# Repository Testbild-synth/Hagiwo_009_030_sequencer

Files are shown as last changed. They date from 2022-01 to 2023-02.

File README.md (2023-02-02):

# HAGIWO 6 Channel Sequencer / Euclidean Rhythm Sequencer

Gif of the sequencer running

This project is a through hole PCB version the HAGIWO 009 [six channel gate sequencer](https://www.youtube.com/watch?v=YszdC8YdFl0&t=29s) and 030 [euclidean rythm sequencer](https://www.youtube.com/watch?v=lkoBfiq6KPY) eurorack synth modules. the modules run on an Arduino Nano and uses a [0.96 inch Oled I2C Display](https://www.ebay.de/itm/255303518853). The exact brand is not important, just make sure it is 128/64 pixels and has an SSD1306 driver.
Also, pinout should match the one specified on the PCB:
I saw that there are some modules that have VCC-GND-SCL-SDA, but we need GND-VCC-SCL-SDA

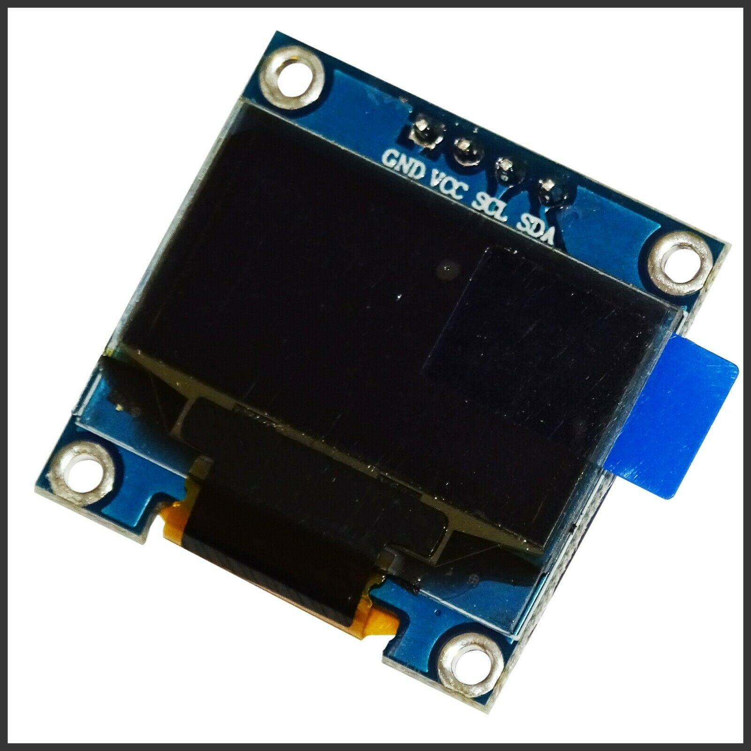
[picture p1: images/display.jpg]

Since both modules use the same hardware, I made it so that the panel pcb is flippable to reflect both functions.

## Status: Don't build this right now, new revision is coming soon!

## PCB and Hardware

You can find the schematic and BOM in the root folder.
For the PCBs, the module has one circuit PCB and one panel PCB. 
You can order them on any common PCB manufacturing service, I used [JLCPCB](https://jlcpcb.com/).
Standard settings should be fine, but if you have exposed copper on the panel you should go with a lead free surface finish (ENIG/Leadfree HASL).

If the panel sizes are not recognized correctly (may happen with my export sometimes) just put 128.5x30.

Use the panel_pcb.zip gerbers if you want a panel with exposed solder mask (so silver letters for title) but then make sure to choose a lead free finish cause health reasons.
If you don't want that, use the "panel_no_silver.zip" version.

The panel PCB is switchable to reflect the function depending on the firmware you want to use.    

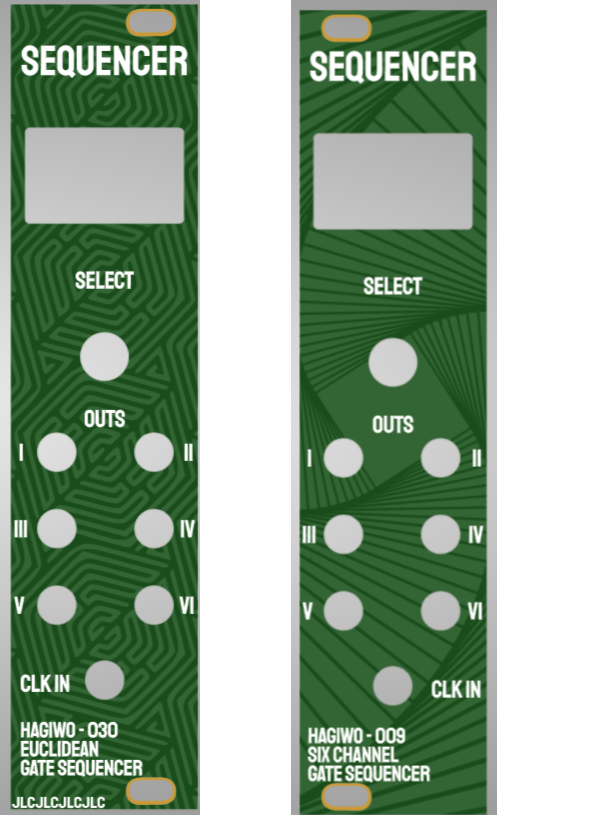
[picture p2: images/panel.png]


## Assembly Instructions

The PCB is relatively simple to build, all the components are through-hole soldering.
It is easiest to start first with the resistors and capacitors, then the headers, and then the jacks at the end.    

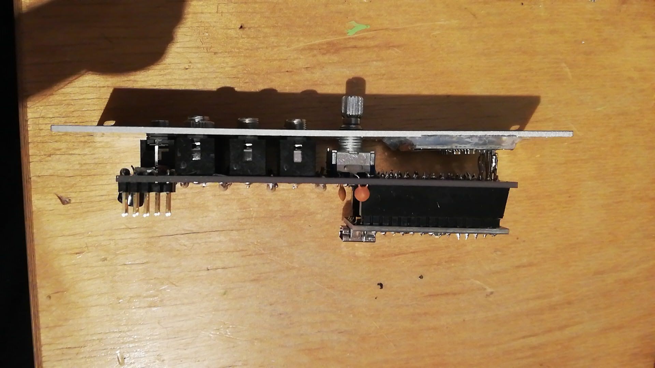
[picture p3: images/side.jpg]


The only thing that is a bit tricky is the screen, since depending on your components it can stand out on the top. 
To prevent this, you can try soldering the display directly on the PCB.    

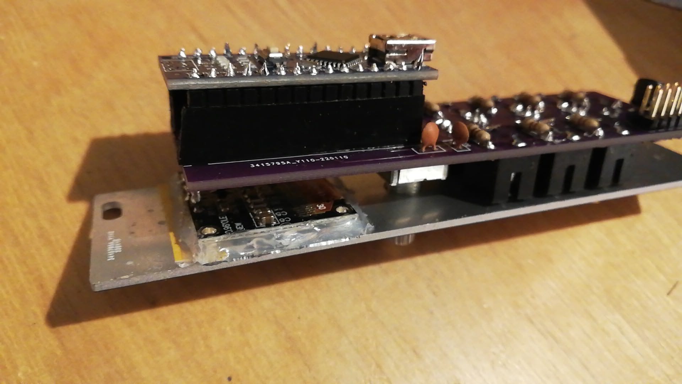
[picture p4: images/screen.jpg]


Another optional but good idea is glueing the screen to the panel first before mounting to ensure it is positioned directly behind the cutout.
Downside to glueing is obviously not being able to flip the panel when flashing the firmware so only do it if you build two or are sure you dont need the other side of the panel.

## Arduino Code and Testing

There are three Arduino files included in this project:
- The project file for the six channel drum sequencer (six_channel_sequencer.ino)
- The project file for the euclidean sequencer        (euclid_sequencer.ino)
- A file for testing in/outputs to make sure you soldered everything correctly (test_circuit.ino). This file prints to the serial to test inputs and sets the digital outputs.

You need the [Adafruit_SSD1306](https://www.arduino.cc/reference/en/libraries/adafruit-ssd1306/) and [encoder](https://www.arduino.cc/reference/en/libraries/encoder/) libraries.
I also changed it such that is uses FastGPIO instead of DigitalRead (to recude latency, which was probably not a concern in the first place but I do it in all my arduino projects). See the [FastGPIO](https://github.com/pololu/fastgpio-arduino) repo.

One important change from HAGIWO's code is the introduction of the parameter ENCODER_COUNT_PER_ROTATION. 
Rotation encoders come in different versions, some have one click per rotation, some have two, others even have four. If you see multiple messages during a single turn while running the test_circuit file, set this parameter higher in all files before uploading.

For the six channel sequencer, there are preprogrammed pattern banks you can change (bnk1_ptn, bnk2_ptn, etc.). The patterns are in hexadecimal and represent 16 binary numbers. So for example if the number says 0x8888, this means 1000100010001000, meaning a four on the floor pattern. Use a [hex to binary converter](https://www.rapidtables.com/convert/number/hex-to-binary.html) to help you convert it.

HAGIWO's version only updates the screen when the clock comes in, but I think this makes for a bad user experience so I changed it to update when you turn the encoder as well. 

## TODO:
- Maybe add more rhythm patterns to 6 channel sequencer (taking suggestions here if people want to help me with the work)

## Successful builds
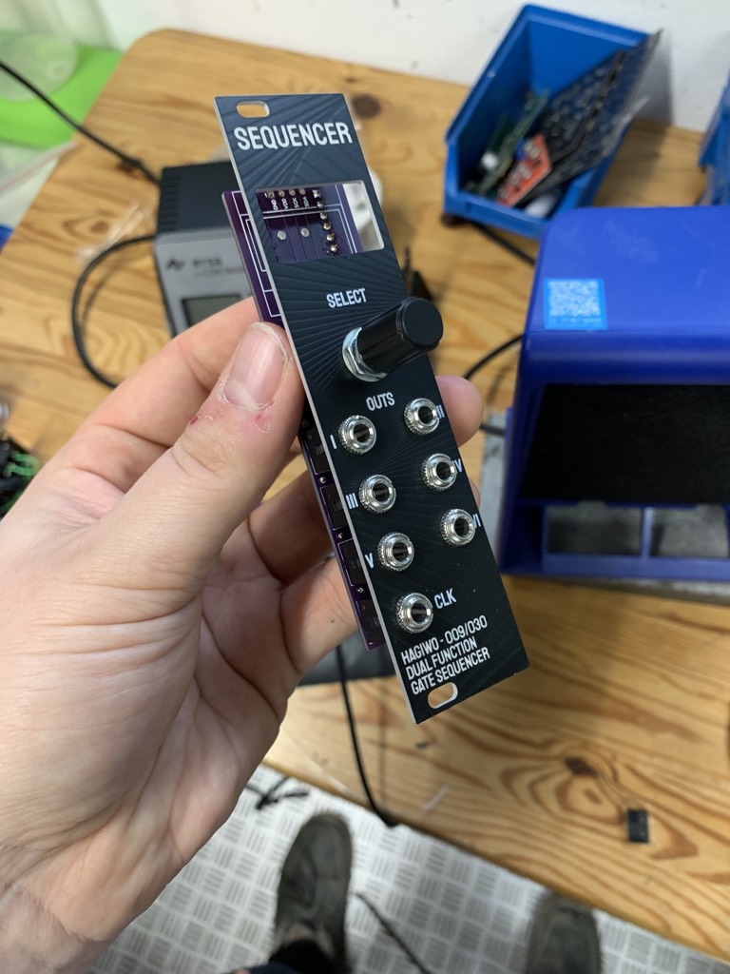
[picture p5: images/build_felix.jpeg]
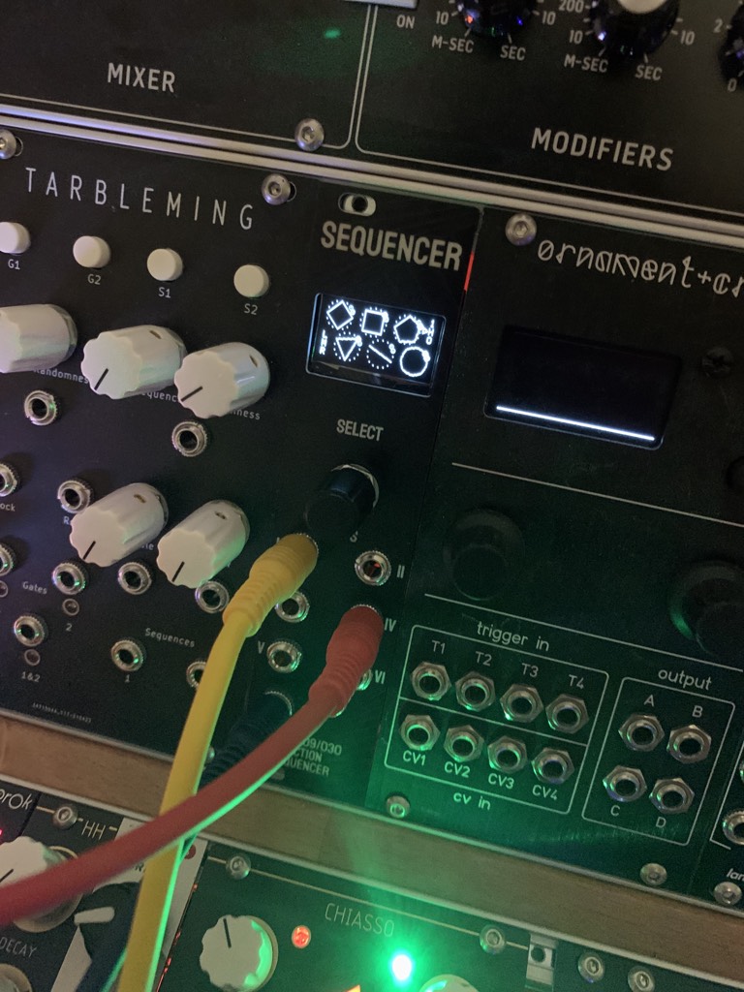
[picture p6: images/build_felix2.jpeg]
 

By Felix W.

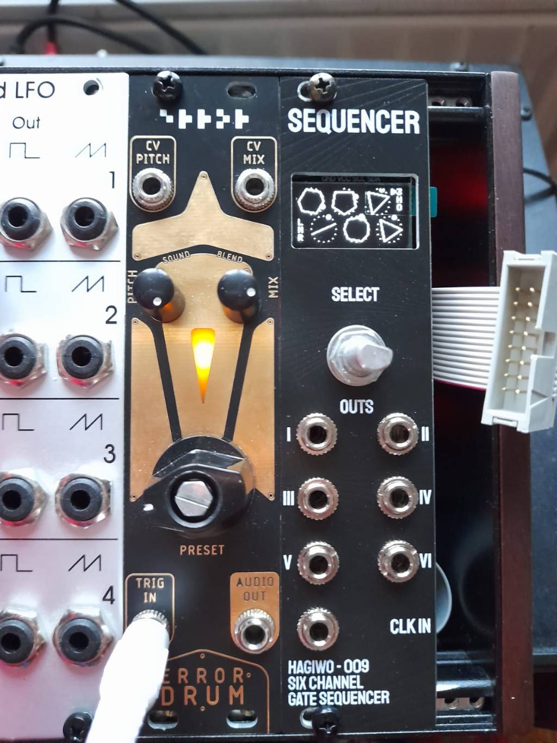
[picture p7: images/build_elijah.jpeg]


By Elija

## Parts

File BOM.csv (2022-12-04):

Name | Designator
ALPS_ENCODER+PUSHSWITCH | ENC
10n | C1,C2
10u | C3
BAT43 | D1,D2
EURORACK_POWERHEADER_V2 | EP1
0.96OLEDDisplay SSD1306 | H1
THONKICONN_1 | J1-J7
2.2k | R1,R2,R3,R4,R5,R6,R9
3k3 | R7,R8
100k | R10
ARDUINO_NANO | U1

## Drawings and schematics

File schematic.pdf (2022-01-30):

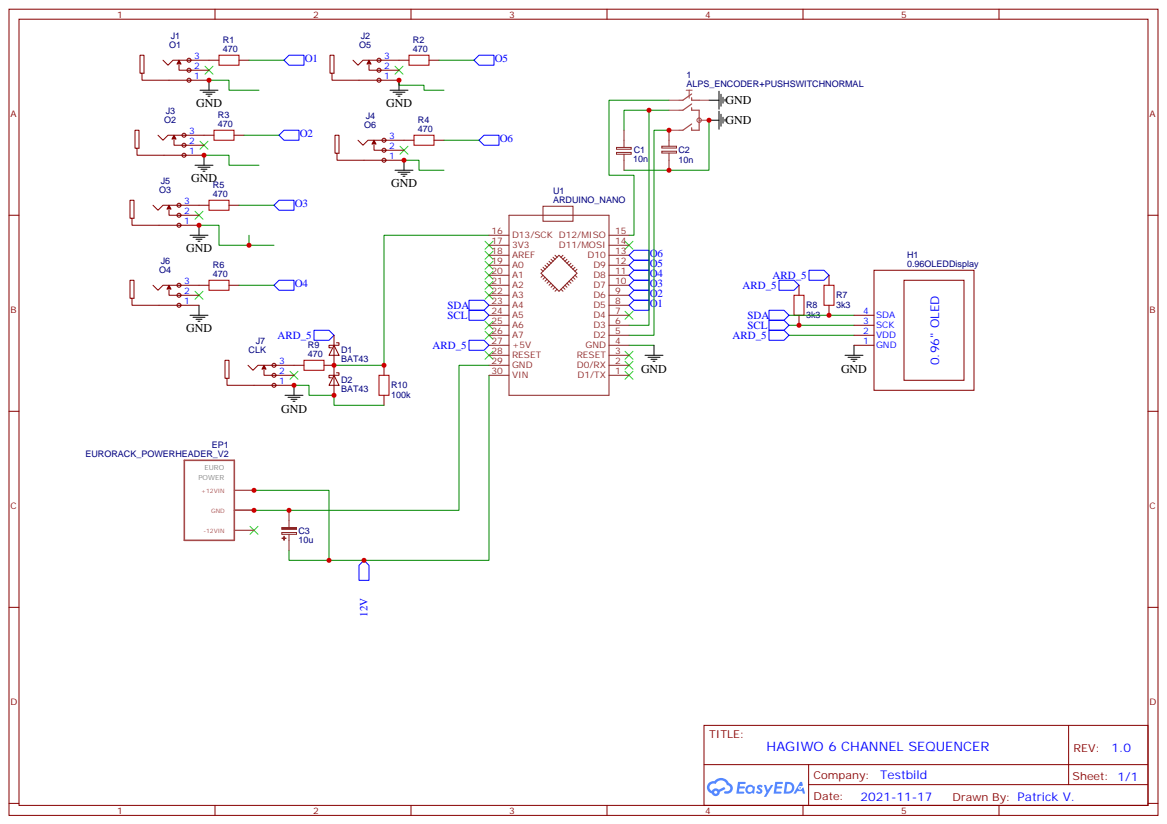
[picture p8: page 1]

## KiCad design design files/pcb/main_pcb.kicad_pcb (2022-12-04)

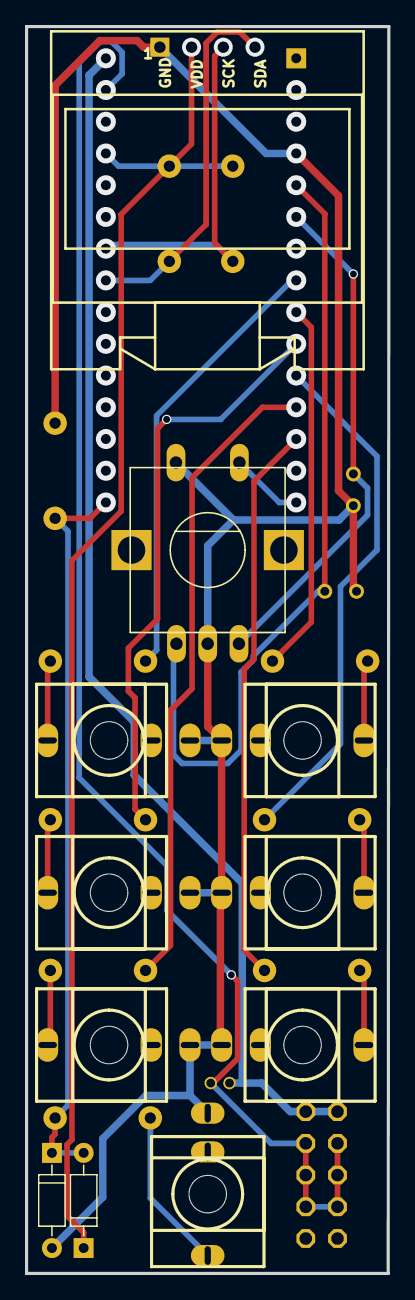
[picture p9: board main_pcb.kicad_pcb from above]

Board: 2 copper layers, 29.0 x 99.8 mm, 24 parts (0 on the bottom side), 14 nets.

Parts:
1: ALPS_ENCODER+PUSHSWITCHNORMAL; ENCODER+SWITCH
C1, C2: 10n; RAD-0.1
C3: 10u; CAP-D4.0×F1.5
D1, D2: BAT43; D_DO-35_SOD27_P7.62MM_HORIZONTAL
EP1: EURORACK_POWERHEADER_V2; EURORACK_POWER_V2
J1: O1; THONKICONN_1
J2: O5; THONKICONN_1
J3: O2; THONKICONN_1
J4: O6; THONKICONN_1
J5: O3; THONKICONN_1
J6: O4; THONKICONN_1
J7: CLK; THONKICONN_1
R1, R2, R3, R4, R5, R6, R9: 2.2k; R_AXIAL-0.3
R7, R8: 3k3; R_AXIAL-0.3
R10: 100k; R_AXIAL-0.3

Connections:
12V: C3.1, EP1.12
ARD_5: D1.1, R7.1, R8.1
C1_2: 1.B, C1.2
C2_1: 1.A, C2.1
EP1_GND0: C3.2, EP1.GND0, EP1.GND1, EP1.GND2, EP1.GND3, EP1.GND4, EP1.GND5
GND: 1.C, 1.D, C1.1, C2.2, D2.2, J1.1, J2.1, J3.1, J4.1, J5.1, J6.1, J7.1, R10.2
R1_2: J1.3, R1.2
R2_2: J2.3, R2.2
R3_2: J3.3, R3.2
R4_2: J4.3, R4.2
R5_2: J5.3, R5.2
R6_2: J6.3, R6.2
R9_2: J7.3, R9.2
R10_1: D1.2, D2.1, R9.1, R10.1

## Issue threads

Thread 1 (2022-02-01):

Would it be posible to access your design files?

KeLaiFu, 2022-02-01:
First of all, thanks for making the Hagiwo modules accessable to those of us too lazy to use veroboard, really happy to see them being upped to github.

I have just ordred a few of his modules from another chap doing the same and in the process I edited them a little, just to make the jack spacing and screen height etc the same as some of my current modules in the rack. A bit of a first world OCD problem I know, but would it be posible to get the kicad/eagle files of the ones you made added to the repo so I could do the same and keep everthing in the same style?

Testbild-synth, 2022-02-01:
Hey :) So I use easyeda for my pcbs and inkscape for my panels. The panels I can give you either as an inkscape project file or converted to a kicad project, for the pcbs I have too look what the best way to export them is. I think easyeda does kicad and eagle export but I've tried it once and it seemed a bit buggy. with that in mind, what do you think is the best format to upload the design files

KeLaiFu, 2022-02-02:
I've used the web based easyeda > kicad converter without problems, so just uploading your files without any changes should be fine.

Testbild-synth, 2022-02-03:
@KeLaiFu I uploaded all the files, check again and if these are helpful for you I can close the issue

KeLaiFu, 2022-02-04:
I had a quick look as I am on my way out of the house, looks fine, thanks so much!

Closed 2022-02-07.

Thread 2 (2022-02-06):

Gerber and Production file mismatch

DeadPanne, 2022-02-06:
To start, Thank you for your amazing work on the HAGIWO designs!
I was planning on doing some modification of the PCB, but when looking at the design files for this repo, it seems like you've uploaded the production files for the [Eurorack Quantizer](https://github.com/Testbild-synth/HAGIWO-029-033-Eurorack-quantizer) as it uses a Seeeduino Xiao in the PCB

Thanks in advance

Testbild-synth, 2022-02-07:
ok sorry, I uploaded multiple projects these last few days and must have gotten confused. now it should be fine

Testbild-synth, 2022-02-09:
i will close this for now, if I made another mistake just tell me

Closed 2022-02-09.

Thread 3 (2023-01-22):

The sequences doesn't respond to the clock signal

dubbeljoe2002, 2023-01-22:
When I connect all, programis running, but is not responding to the clock signal.
checked hardware and  solder joins, all OK.

Testbild-synth, 2023-01-22:
So the clock input is connected to D13, which on some arduinos causes problems when used as an input because it is also connected to the internal LED. I will change it to use a different pin in the next revision and leave this issue open until then, but for now a quick fix you can try is scratching off or desoldering the LED on your nano (the one with the L next to it).

More information is here: https://forum.arduino.cc/t/arduino-nano-pin-d13-usage/474254

Testbild-synth, 2023-01-22:
Also I just saw that there might be a ground connection issue, please make sure that on the board you have the jack grounds are properly connected to the arduino ground and the power ground

dubbeljoe2002, 2023-01-26:
> Also I just saw that there might be a ground connection issue, please make sure that on the board you have the jack grounds are properly connected to the arduino ground and the power ground

thanks for the tips.
I desoldered the L Led on my aliexpress arduino nano and checked the ground connectors.
unfortunately if did not give a solution.
Don't feel obligated to fix this. Maybe it gives me the right push to dive into the code and learn something ;-)

dtk1985, 2024-11-25:
Hi @Testbild-synth , first of all thanks for the gerbers. I just manged to solder up the board which I had lying around for a year. I think I had the same problem as @dubbeljoe2002, the module was not responding to the clock signal from the Meebilt LFO at first. But after removing the arduino's LED resistor and making sure all grounds are connected, it started working. Yay!

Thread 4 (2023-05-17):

Please move outputs 2,4,6 to PWM pins and add optional LPFs

BenignCremator, 2023-05-17:
What I would like to be able to do is write alternative code for this module that would group pairs of outputs (1 and 2, 3 with 4, 5 with 6) into gate and CV pairs, allowing the module to output three tonal channels instead of six atonal ones.  For this, output 2, 4, and 6 need to be moved onto PWM pins.  If I am reading the schematic correctly, outputs 2 and 6 are currently on PWM pins, and only D4 needs to be changed.  One way to do this is by swapping D8 and D9, or moving outputs 4, 5, and 6 to D9,  D10, and D11.  Also, since this would require using PWM output to generate a CV signal, low pass filters would be a good idea on those pins.  A simple resistor-capacitor filter should suffice, though adding an on-board op-amp for buffering would be a nice to have.  Is this a do-able and reasonable?  Please let me know and thanks in advance.

Testbild-synth, 2023-05-17:
hi,
first of all thank you for your interest in the module and willingness to contribute!

since I planned to do a redesign of this anyway I might as well do that.
keep in mind that running the PWM loops with an I2C screen connection at the same time might get a bit iffy in terms of programming it (I have used SPI screens before and had quite a few problems with audio artifacts/noise being introduced.) If you want we can coordinate on this, I'd be happy to give you other contact details :)

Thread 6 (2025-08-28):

Low output to trigger drum modules

mjlouer-png, 2025-08-28:
Hi Testbild.

Ive build the gate sequencer from Hagiwo a few months ago and it works but it has issues.
The main one is that when i turn on my modular synth, the oled stays black. The module does not start. After uploading the code everything works as normal. Then after some time (sometimes a few hours, days or weeks) for some yet unknown reason the module does not start. Re-uploading the sketch and boom! It works. So apperantly the Arduino Nano loses its programming.

While searching the internet i stumbled upon your github and tried your code.
The Arduino starts, i see the dots on the screen but it does nog trigger any of my, mostly Moritz Klein's drum modules. So apperantly the gate output voltages are too low??. For testing i tried the HIP bass drum module as the THUD sets the treshold and when fully open the potmeter, it starts to trigger. So the module works but to low output. How can i increase or set out voltage tresholds? Some line in the code i hope?

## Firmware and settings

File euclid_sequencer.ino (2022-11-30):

//Encoder setting
#define  ENCODER_OPTIMIZE_INTERRUPTS //countermeasure of encoder noise
#include <Encoder.h>
#include <FastGPIO.h>

//Oled setting
#include<Wire.h>
#include<Adafruit_GFX.h>
#include<Adafruit_SSD1306.h>

#define OLED_ADDRESS 0x3C
#define SCREEN_WIDTH 128
#define SCREEN_HEIGHT 64
#define ENCODER__PIN1 2
#define ENCODER_PIN2  3
#define ENCODER_SW_PIN 12
#define CLK_PIN 13
#define ENCODER_COUNT_PER_CLICK 4

#define OUT_CH1 5
#define OUT_CH2 6
#define OUT_CH3 7
#define OUT_CH4 8
#define OUT_CH5 9
#define OUT_CH6 10

Adafruit_SSD1306 display(SCREEN_WIDTH, SCREEN_HEIGHT, &Wire, -1);

//rotery encoder
Encoder myEnc(ENCODER__PIN1, ENCODER_PIN2);//use 3pin 2pin
int oldPosition  = -999;
int newPosition = -999;
int i = 0;

//push button
bool sw = 0;//push button
bool old_sw;//countermeasure of sw chattering
unsigned long sw_timer = 0;//countermeasure of sw chattering



//each channel param
byte hits[6] = { 4, 4, 5, 3, 2, 16};//each channel hits
byte offset[6] = { 0, 2, 0, 8, 3, 9};//each channele step offset
bool mute[6] = {0, 0, 0, 0, 0, 0}; //mute 0 = off , 1 = on
byte limit[6] = {16, 16, 16, 16, 16, 16};//eache channel max step

//Sequence variable
byte j = 0;
byte k = 0;
byte m = 0;
byte buf_count = 0;

const static byte euc16[17][16] PROGMEM = {//euclidian rythm
 {0, 0, 0, 0, 0, 0, 0, 0, 0, 0, 0, 0, 0, 0, 0, 0},
 {1, 0, 0, 0, 0, 0, 0, 0, 0, 0, 0, 0, 0, 0, 0, 0},
 {1, 0, 0, 0, 0, 0, 0, 0, 1, 0, 0, 0, 0, 0, 0, 0},
 {1, 0, 0, 0, 0, 1, 0, 0, 0, 0, 1, 0, 0, 0, 0, 0},
 {1, 0, 0, 0, 1, 0, 0, 0, 1, 0, 0, 0, 1, 0, 0, 0},
 {1, 0, 0, 1, 0, 0, 1, 0, 0, 1, 0, 0, 1, 0, 0, 0},
 {1, 0, 0, 1, 0, 1, 0, 0, 1, 0, 0, 1, 0, 1, 0, 0},
 {1, 0, 0, 1, 0, 1, 0, 1, 0, 0, 1, 0, 1, 0, 1, 0},
 {1, 0, 1, 0, 1, 0, 1, 0, 1, 0, 1, 0, 1, 0, 1, 0},
 {1, 0, 1, 1, 0, 1, 0, 1, 0, 1, 1, 0, 1, 0, 1, 0},
 {1, 0, 1, 1, 0, 1, 0, 1, 1, 0, 1, 1, 0, 1, 0, 1},
 {1, 0, 1, 1, 0, 1, 1, 0, 1, 1, 0, 1, 1, 0, 1, 1},
 {1, 0, 1, 1, 1, 0, 1, 1, 1, 0, 1, 1, 1, 0, 1, 1},
 {1, 0, 1, 1, 1, 1, 0, 1, 1, 1, 1, 0, 1, 1, 1, 1},
 {1, 0, 1, 1, 1, 1, 1, 1, 1, 0, 1, 1, 1, 1, 1, 1},
 {1, 1, 1, 1, 1, 1, 1, 1, 1, 1, 1, 1, 1, 1, 1, 0},
 {1, 1, 1, 1, 1, 1, 1, 1, 1, 1, 1, 1, 1, 1, 1, 1}
};
bool offset_buf[6][16];//offset buffer , Stores the offset result

bool trg_in = 0;//external trigger in H=1,L=0
bool old_trg_in = 0;
byte playing_step[6] = {0, 0, 0, 0, 0, 0}; //playing step number , CH1,2,3,4,5,6
unsigned long gate_timer = 0;//countermeasure of sw chattering

//display param
byte select_menu = 0;//0=CH,1=HIT,2=OFFSET,3=LIMIT,4=MUTE,5=RESET,
byte select_ch = 0;//0~5 = each channel -1 , 6 = random mode

unsigned int last_refresh = 0;
const int  max_refresh_time = 70;
bool disp_refresh = 1;//0=not refresh display , 1= refresh display , countermeasure of display refresh bussy

const byte graph_x[6] = {0, 40, 80, 15, 55, 95};//each chanel display offset
const byte graph_y[6] = {0, 0,  0,  32, 32, 32};//each chanel display offset

byte line_xbuf[17];//Buffer for drawing lines
byte line_ybuf[17];//Buffer for drawing lines

const byte x16[16] = {15,  21, 26, 29, 30, 29, 26, 21, 15, 9,  4,  1,  0,  1,  4,  9};//Vertex coordinates
const byte y16[16] = {0,  1,  4,  9,  15, 21, 26, 29, 30, 29, 26, 21, 15, 9,  4,  1};//Vertex coordinates


//random assign
byte hit_occ[6] = {0, 10, 20, 20, 40, 80}; //random change rate of occurrence
byte off_occ[6] = {10, 20, 20, 30, 40, 20}; //random change rate of occurrence
byte mute_occ[6] = {20, 20, 20, 20, 20, 20}; //random change rate of occurrence
byte hit_rng_max[6] = {0, 14, 16, 8, 9, 16}; //random change range of max
byte hit_rng_min[6] = {0, 13, 6, 1, 5, 10}; //random change range of max

byte bar_now = 1;//count 16 steps, the bar will increase by 1.
byte bar_max[4] = {2, 4, 8, 16} ;//selectable bar
byte bar_select = 1;//selected bar
byte step_cnt = 0;//count 16 steps, the bar will increase by 1.

void setup() {
 // OLED setting
 display.begin(SSD1306_SWITCHCAPVCC, 0x3C);
 display.setTextSize(1);
 display.setTextColor(WHITE);
 OLED_display();

 //pin mode setting
 FastGPIO::Pin<ENCODER_SW_PIN>::setInputPulledUp(); //BUTTON
 FastGPIO::Pin<CLK_PIN>::setInput(); // CLK
}

void loop() {
 
 old_trg_in = trg_in;
 oldPosition = newPosition;
 //-----------------Rotery encoder read----------------------
 newPosition = myEnc.read()/ENCODER_COUNT_PER_CLICK;

 if ( newPosition   < oldPosition ) {//turn left
   oldPosition = newPosition;
   disp_refresh = 1;//Enable while debugging.
   if (select_menu != 0) {
     select_menu --;
   }
 }

 else if ( newPosition    > oldPosition ) {//turn right
   oldPosition = newPosition;
   disp_refresh = 1;//Enable while debugging.
   select_menu ++;
 }
 if (select_ch != 6) { // not random mode
   select_menu = constrain(select_menu, 0, 5);
 }
 else  if (select_ch == 6) { // random mode
   select_menu = constrain(select_menu, 0, 1);
 }

 //-----------------push button----------------------

 sw = 1;
 if ((!FastGPIO::Pin<ENCODER_SW_PIN>::isInputHigh()) && ( sw_timer + 300 <= millis() )) { //push button on ,Logic inversion , sw_timer is countermeasure of chattering
   sw_timer = millis();
   sw = 0;
   disp_refresh = 1;//Enable while debugging.
 }

 if (sw == 0) { //push button on
   switch (select_menu) {
     case 0: //select chanel
       select_ch ++;
       if (select_ch >= 7) {
         select_ch = 0;
       }
       break;

     case 1: //hits
       if (select_ch != 6) { // not random mode
         hits[select_ch]++ ;
         if (hits[select_ch] >= 17) {
           hits[select_ch] = 0;
         }
       }
       else  if (select_ch == 6) { // random mode
         bar_select ++;
         if (bar_select >= 4) {
           bar_select = 0;
         }
       }
       break;

     case 2: //offset
       offset[select_ch]++ ;
       if (offset[select_ch] >= 16) {
         offset[select_ch] = 0;
       }
       break;

     case 3: //limit
       limit[select_ch]++ ;
       if (limit[select_ch] >= 17) {
         limit[select_ch] = 0;
       }

       break;

     case 4: //mute
       mute[select_ch] = !mute[select_ch] ;
       break;

     case 5: //reset
       for (k = 0; k <= 5; k++) {
         playing_step[k] = 0;
       }
       break;
   }
 }

 //-----------------offset setting----------------------
 for (k = 0; k <= 5; k++) { //k = 1~6ch
   for (i = offset[k]; i <= 15; i++) {
     offset_buf[k][i - offset[k]] = (pgm_read_byte(&(euc16[hits[k]][i]))) ;
   }

   for (i = 0; i < offset[k]; i++) {
     offset_buf[k][16 - offset[k] + i] = (pgm_read_byte(&(euc16[hits[k]][i])));
   }
 }

 //-----------------trigger detect & output----------------------
 trg_in = FastGPIO::Pin<CLK_PIN>::isInputHigh();//external trigger in
 if (old_trg_in == 0 && trg_in == 1) {
   gate_timer = millis();
   for (i = 0; i <= 5; i++) {
     playing_step[i]++;      //When the trigger in, increment the step by 1.
     if (playing_step[i] >= limit[i]) {
       playing_step[i] = 0;  //When the step limit is reached, the step is set back to 0.
     }
   }
   for (k = 0; k <= 5; k++) {//output gate signal
     if (offset_buf[k][playing_step[k]] == 1 && mute[k] == 0) {
       switch (k) {
         case 0:
           FastGPIO::Pin<OUT_CH1>::setOutputValue(HIGH);
           break;

         case 1:
           FastGPIO::Pin<OUT_CH2>::setOutputValue(HIGH);
           break;

         case 2:
           FastGPIO::Pin<OUT_CH3>::setOutputValue(HIGH);
           break;

         case 3:
           FastGPIO::Pin<OUT_CH4>::setOutputValue(HIGH);
           break;

         case 4:
           FastGPIO::Pin<OUT_CH5>::setOutputValue(HIGH);
           break;

         case 5:
           FastGPIO::Pin<OUT_CH6>::setOutputValue(HIGH);
           break;
       }
     }
   }
   // if the bpm is too high we want to still have output but not update the screen so that the arduino is not busy
   if((millis()-last_refresh) > max_refresh_time){
      disp_refresh = 1;
      last_refresh = millis();
   }
   //Updates the display where the trigger was entered.If it update it all the time, the response of gate on will be worse.

   if (select_ch == 6) {// random mode setting
     step_cnt ++;
     if (step_cnt >= 16) {
       bar_now ++;
       step_cnt = 0;
       if (bar_now > bar_max[bar_select]) {
         bar_now = 1;
         Random_change();
       }
     }
   }
 }

 if  (gate_timer + 100 <= millis()) { //off all gate , gate time is 10msec
   FastGPIO::Pin<OUT_CH1>::setOutputValue(LOW);
   FastGPIO::Pin<OUT_CH2>::setOutputValue(LOW);
   FastGPIO::Pin<OUT_CH3>::setOutputValue(LOW);
   FastGPIO::Pin<OUT_CH4>::setOutputValue(LOW);
   FastGPIO::Pin<OUT_CH5>::setOutputValue(LOW);
   FastGPIO::Pin<OUT_CH6>::setOutputValue(LOW);
 }


 if (disp_refresh == 1) {
   OLED_display();//refresh display
   disp_refresh = 0;
 }
}

void Random_change() { // when random mode and full of bar_now ,
 for (k = 1; k <= 5; k++) {

   if (hit_occ[k] >= random(1, 100)) { //hit random change
     hits[k] = random(hit_rng_min[k], hit_rng_max[k]);
   }

   if (off_occ[k] >= random(1, 100)) { //hit random change
     offset[k] = random(0, 16);
   }

   if (mute_occ[k] >= random(1, 100)) { //hit random change
     mute[k] = 1;
   }
   else if (mute_occ[k] < random(1, 100)) { //hit random change
     mute[k] = 0;
   }
 }
}

void OLED_display() {
 display.clearDisplay();
 //-------------------------euclidean circle display------------------
 //draw setting menu
 display.setCursor(120, 0);
 if (select_ch != 6) { // not random mode
   display.print(select_ch + 1);
 }
 else if (select_ch == 6) { //random mode
   display.print("R");
 }
 display.setCursor(120, 9);
 if (select_ch != 6) { // not random mode
   display.print("H");
 }
 else if (select_ch == 6) { //random mode
   display.print("O");
 }
 display.setCursor(120, 18);
 if (select_ch != 6) { // not random mode
   display.print("O");
   display.setCursor(0, 36);
   display.print("L");
   display.setCursor(0, 45);
   display.print("M");
   display.setCursor(0, 54);
   display.print("R");
 }


 //random count square
 if (select_ch == 6) { //random mode
   //        display.drawRect(1, 32, 6, 32, WHITE);
   //    display.fillRect(1, 32, 6, 16, WHITE);
   display.drawRect(1, 62 - bar_max[bar_select] * 2, 6, bar_max[bar_select] * 2 + 2, WHITE);
   display.fillRect(1, 64 - bar_now * 2 , 6, bar_max[bar_select] * 2, WHITE);
 }
 //draw select triangle
 if ( select_menu == 0) {
   display.drawTriangle(113, 0, 113, 6, 118, 3, WHITE);
 }
 else  if ( select_menu == 1) {
   display.drawTriangle(113, 9, 113, 15, 118, 12, WHITE);
 }

 if (select_ch != 6) { // not random mode
   if ( select_menu == 2) {
     display.drawTriangle(113, 18, 113, 24, 118, 21, WHITE);
   }
   else  if ( select_menu == 3) {
     display.drawTriangle(12, 36, 12, 42, 7, 39, WHITE);
   }
   else  if ( select_menu == 4) {
     display.drawTriangle(12, 45, 12, 51, 7, 48, WHITE);
   }
   else  if ( select_menu == 5) {
     display.drawTriangle(12, 54, 12, 60, 7, 57, WHITE);
   }
 }

 //draw step dot
 for (k = 0; k <= 5; k++) { //k = 1~6ch
   for (j = 0; j <= limit[k] - 1; j++) { // j = steps
     display.drawPixel(x16[j] + graph_x[k], y16[j] + graph_y[k], WHITE);
   }
 }

 //draw hits line : 2~16hits
 for (k = 0; k <= 5; k++) { //ch count
   buf_count = 0;
   for (m = 0; m < 16; m++) {
     if (offset_buf[k][m] == 1) {
       line_xbuf[buf_count] = x16[m] + graph_x[k];//store active step
       line_ybuf[buf_count] = y16[m] + graph_y[k];
       buf_count++;
     }
   }

   for (j = 0; j < buf_count - 1; j++) {
     display.drawLine(line_xbuf[j], line_ybuf[j], line_xbuf[j + 1], line_ybuf[j + 1], WHITE);
   }
   display.drawLine(line_xbuf[0], line_ybuf[0], line_xbuf[j], line_ybuf[j], WHITE);
 }
 for (j = 0; j < 16; j++) {//line_buf reset
   line_xbuf[j] = 0;
   line_ybuf[j] = 0;
 }

 //draw hits line : 1hits
 for (k = 0; k <= 5; k++) { //ch count
   buf_count = 0;
   if (hits[k] == 1) {
     display.drawLine(15 + graph_x[k], 15 + graph_y[k], x16[offset[k]] + graph_x[k], y16[offset[k]] + graph_y[k], WHITE);
   }
 }

 //draw play step circle
 for (k = 0; k <= 5; k++) { //ch count
   if (mute[k] == 0) { //mute on = no display circle
     if (offset_buf[k][playing_step[k]] == 0) {
       display.drawCircle(x16[playing_step[k]] + graph_x[k], y16[playing_step[k]] + graph_y[k], 2, WHITE);
     }
     if (offset_buf[k][playing_step[k]] == 1) {
       display.fillCircle(x16[playing_step[k]] + graph_x[k], y16[playing_step[k]] + graph_y[k], 3, WHITE);
     }
   }
 }
 display.display();
}

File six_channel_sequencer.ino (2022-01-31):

//----------------ライブラリの読み出し---------------------------
//EEPROM用ライブラリ
#include <EEPROM.h>

//エンコーダ用ライブラリ
#define  ENCODER_OPTIMIZE_INTERRUPTS //エンコーダノイズ対策
#include <Encoder.h>
#include <FastGPIO.h>


//OLED用ライブラリ
#include<Wire.h>
#include<Adafruit_GFX.h>
#include<Adafruit_SSD1306.h>

#define OLED_ADDRESS 0x3C
#define SCREEN_WIDTH 128//128が推奨表示
#define SCREEN_HEIGHT 64//64が推奨表示 

#define OLED_ADDRESS 0x3C
#define SCREEN_WIDTH 128
#define SCREEN_HEIGHT 64
#define ENCODER_PIN1 2
#define ENCODER_PIN2  3
#define ENCODER_SW_PIN 12
#define CLK_PIN 13
#define ENCODER_COUNT_PER_ROTATION 4

#define OUT_CH1 5
#define OUT_CH2 6
#define OUT_CH3 7
#define OUT_CH4 8
#define OUT_CH5 9
#define OUT_CH6 10

//----------------変数の定義---------------------------
byte step_count = 0; //clock in毎に1繰り上がり。17になると1に戻る。増えた時にOUTPUTをONする。
byte clock_in = 0 ; //外部クロックの入力状態。H=1,L=0
byte old_clock_in = 0 ; //0→1を認識するための変数

unsigned int ch1_step = 0x8888; //テスト用
byte CH1_output = 0 ;
byte CH1_mute = 0 ;//0=ミュートしない、1=ミュートする

unsigned int ch2_step = 0x0808; //テスト用
byte CH2_output = 0 ;
byte CH2_mute = 0 ;//0=ミュートしない、1=ミュートする

unsigned int ch3_step = 0xCCCC; //テスト用
byte CH3_output = 0 ;
byte CH3_mute = 0 ;//0=ミュートしない、1=ミュートする

unsigned int ch4_step = 0x2222; //テスト用
byte CH4_output = 0 ;
byte CH4_mute = 0 ;//0=ミュートしない、1=ミュートする

unsigned int ch5_step = 0xFFFF; //テスト用
byte CH5_output = 0 ;
byte CH5_mute = 0 ;//0=ミュートしない、1=ミュートする

unsigned int ch6_step = 0x0000; //テスト用
byte CH6_output = 0 ;
byte CH6_mute = 0 ;//0=ミュートしない、1=ミュートする


//ロータリーエンコーダ設定
Encoder myEnc(ENCODER_PIN1, ENCODER_PIN2);//ロータリーエンコーダライブラリ用
int oldPosition  = -999;
int newPosition = -999;
byte enc = 96; //選択中のエンコーダ。初回起動時はMANUAL表示
byte enc_max = 105; //マニュアルモードではmax=99(16*6ch+option3+mute6)。AUTOでは11(MANUAL,genre,fillin,repeat,sw+mute6)
unsigned int enc_bit = 0x00;//

//ボタン設定
byte button = 0;//0=OFF,1=ON
byte old_button = 0;//チャタリング対策
byte button_on = 0;//チャタリング判定後のボタン状態。0=OFF,1=ON

// ディスプレイ変数の宣言
Adafruit_SSD1306 display(SCREEN_WIDTH, SCREEN_HEIGHT, &Wire, -1);

//オプション
byte mode = 0;//0=MANUAL,1=AUTO
byte count_reset = 0;//1でcountが0になる
byte save = 0;//1でseve実行しすぐに0に戻る

byte genre = 0; //パターンジャンル0=techno,1=dub,2=house
byte repeat = 2; //0=4times,1=8times,2=16times,3=32times,4=eternal
byte fillin = 1; //0=OFF,1=ON
byte sw = 0;//0=2,1=4,2=8,3=16,4=eternal

//AUTOモード
int repeat_max = 4;//repeat_doneこの値に達したらフィルイン
int repeat_done = 0; //stepが16になったら繰り上がる。
byte test = 0; //開発用
byte change_bnk1 = 1;//プリセット1
byte change_bnk2 = 1;//プリセット2
byte change_bnk3 = 1;//プリセット3（任意に増やしてOK）
byte sw_max = 1;//se_doneがこの値に達したらパターン変更（ランダム）
byte sw_done = 0;//repeat_maxになったら繰り上がる


//preset step pattern
//[パターンの数][CHの数*2。頭6個が通常時、後ろ6個がfillin]
//16信数はドラムパターンを示す。

//bnk1 TECHNO
const static word bnk1_ptn[8][12] PROGMEM = {
 { 0x8888,  0x0808, 0xDDDD, 0x2222, 0x1000, 0x0022,
   0x8888, 0x88AF, 0xDDDD, 0x2222, 0x1000, 0x0022
 },
 { 0x8888,  0x0808, 0xFFFF, 0x2222, 0x1000, 0x0022,
   0x8888, 0x88AF, 0xFFFF, 0x2222, 0x1000, 0x0022
 },
 { 0x8888,  0x0808, 0xCCCC, 0x2222, 0x1000, 0x0022,
   0x8888, 0x88AF, 0xCCCC, 0x2222, 0x1000, 0x0022
 },
 { 0x8888,  0x0808, 0x4545, 0x2222, 0x1000, 0x0022,
   0x88AF, 0x0808, 0x4545, 0x2222, 0x1000, 0x0022
 },
 { 0x8888,  0x0808, 0xFFFF, 0x2222, 0x1000, 0x0022,
   0x88AF, 0x0808, 0xFFFF, 0x2222, 0x1000, 0x0022
 },
 { 0x8888,  0x0809, 0xDDDD, 0x2222, 0x1000, 0x0022,
   0x0000, 0x0809, 0xDDDD, 0x2222, 0x1000, 0x0022
 },
 { 0x8888,  0x0849, 0xDDDD, 0x2222, 0x1000, 0x0022,
   0x0000, 0x0849, 0xDDDD, 0x2222, 0x1000, 0x0022
 },
 { 0x8888,  0x0802, 0xDDDD, 0x2222, 0x1000, 0x0022,
   0x8896, 0x0869, 0xDDDD, 0x2222, 0x1000, 0x0022
 }
};

//bank2 DUBTECHNO
const static word bnk2_ptn[8][12] PROGMEM = {
 { 0x8888,  0x0808, 0xDDDD, 0x2222, 0x1240, 0x0022,
   0x8888, 0x0809, 0xDDDD, 0x2222, 0x1240, 0x0022
 },
 { 0x8888,  0x0808, 0xFFFF, 0x2222, 0x1240, 0x0022,
   0x000A, 0x0849, 0xDDDD, 0x2222, 0x1000, 0x0022
 },
 { 0x8889,  0x0808, 0xCCCC, 0x2222, 0x1240, 0x0022,
   0x8888, 0x0000, 0xCCCC, 0x2222, 0x1240, 0x0022
 },
 { 0x8889,  0x0808, 0x4545, 0x2222, 0x1240, 0x0022,
   0x8888, 0x0809, 0x4545, 0x2222, 0x1240, 0x0022
 },
 { 0x888C,  0x0808, 0xFFFF, 0x2222, 0x1240, 0x0022,
   0x8888, 0x8888, 0xFFFF, 0x2222, 0x1240, 0x0022
 },
 { 0x888C,  0x0809, 0xDDDD, 0x2222, 0x1240, 0x0022,
   0x999F, 0x0000, 0xDDDD, 0x2222, 0x1240, 0x0022
 },
 { 0x0000,  0x0849, 0xDDDD, 0x2222, 0x1240, 0x0022,
   0x000A, 0x0849, 0xDDDD, 0x2222, 0x1000, 0x0022
 },
 { 0x0000,  0x0802, 0xDDDD, 0x2222, 0x1240, 0x0022,
   0x000A, 0x0802, 0xDDDD, 0x2222, 0x1000, 0x0022
 }
};

//bank3 HOUSE
const static word bnk3_ptn[8][12]PROGMEM = {
 { 0x8888, 0x0808, 0x2222, 0x0000, 0x0040, 0x0101,
   0x8888, 0x88AF, 0x2222, 0x0000, 0x0040, 0x0101
 },
 { 0x888A, 0x0808, 0x2323, 0x0000, 0x0040, 0x0101,
   0x8888, 0x88AF, 0x2323, 0x0000, 0x0040, 0x0101
 },
 { 0x8888, 0x0808, 0xCCCC, 0x2222, 0x0040, 0x0101,
   0x8888, 0x88AF, 0xCCCC, 0x2222, 0x0040, 0x0101
 },
 { 0x888A, 0x0808, 0xCCCC, 0x2222, 0x0040, 0x0101,
   0x8888, 0x88AF, 0xCCCC, 0x2222, 0x0040, 0x0101
 },
 { 0x8888, 0x0808, 0xFFFF, 0x2222, 0x0040, 0x0101,
   0x0000, 0x0808, 0xFFFF, 0x2222, 0x0040, 0x0101
 },
 { 0x888A, 0x0808, 0xFFFF, 0x2222, 0x0040, 0x0101,
   0x0000, 0x0808, 0xFFFF, 0x2222, 0x0040, 0x0101
 },
 { 0x888A, 0x0808, 0xFFFF, 0x2222, 0x0040, 0x4112,
   0x0000, 0x0808, 0xFFFF, 0x2222, 0x0040, 0x4112
 },
 { 0x8888, 0x0808, 0xCCCC, 0x2222, 0x0040, 0x4112,
   0x88AF, 0x0808, 0xCCCC, 0x2222, 0x0040, 0x4112
 }
};

unsigned int last_refresh = 0;
int max_refresh_time = 100;
bool refresh_display = true;

void setup() {


 // ディスプレイの初期化
 display.begin(SSD1306_SWITCHCAPVCC, 0x3C);

 FastGPIO::Pin<ENCODER_SW_PIN>::setInputPulledUp(); //BUTTON
 FastGPIO::Pin<CLK_PIN>::setInput(); // CLK

 //保存データの読み出し
 ch1_step = EEPROM.read(1) * 256 + EEPROM.read(2);
 ch2_step = EEPROM.read(3) * 256 + EEPROM.read(4);
 ch3_step = EEPROM.read(5) * 256 + EEPROM.read(6);
 ch4_step = EEPROM.read(7) * 256 + EEPROM.read(8);
 ch5_step = EEPROM.read(9) * 256 + EEPROM.read(10);
 ch6_step = EEPROM.read(11) * 256 + EEPROM.read(12);

 OLED_display();
}
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

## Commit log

2022-02-03 consistent folder structure and uploaded kicad files
    [control_pcb.kicad_pcb, hagiwo_double_seq.kicad_pcb, main_pcb.kicad_pcb]
2022-02-07 uploaded correct design files
    [main_pcb.kicad_pcb]
2022-10-06 new symmetric pcb and panel
    [hagiwo_double_seq.kicad_pcb, main_pcb.kicad_pcb]
2022-12-04 bigger resistors
    [BOM.csv, main_pcb.kicad_pcb]
